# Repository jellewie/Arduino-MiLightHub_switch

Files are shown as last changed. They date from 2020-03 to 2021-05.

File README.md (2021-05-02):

# ==========

# Depricated!

# ==========

This project is stalled, and here for archieving reasons.
Altough not hardware compatible (buttons inversed) and not softSettings compatible (the order and they have changed), it is recommened to update if required. Do not start new projects with this repo this one is unsuported from now on!!
[smart-home-switch](https://github.com/jellewie/Arduino-smart-home-switch)

# ==========

# Arduino-MiLightHub_switch
 MilightHub https://github.com/sidoh/esp8266_milight_hub

# What you need
ESP8266 with esp8266_milight_hub (and it's IP ofc.)

[ESP32](https://dl.espressif.com/dl/package_esp32_index.json)

[PCB](https://easyeda.com/jellewietsma/smart-home-switch)

# How it works
Make sure the esp8266_milight_hub is already set-up and working, and you know it's IP.

Make sure you have an ESP with the PCB, you can also make one yourself but mine is linked in this project (make sure to read the schematics, they should explain themself)

Make sure to enable SecondSwitch if you have 2 sets of 4 buttons (this can't be done later).

You can either setup the settings like SSID and passwords and such in the code, but you can also just upload the sketch and power it on and set it up: 
It will go into APMODE (since it can’t connect to WIFI) connect to it and go to it's IP (192.168.4.1)
You will get a window with SSID Wi-Fi name, password, the milight hub IP, LightID, LightType, and lightGroup. Change or fill these in and submit. 
The ESP will save these settings and reboot (note that the 4 commands to send to the hub are also stored in here) (Leaving fields blank will skip updating them)

# LED feedback
There a lot of blinking patterns, but I tried to list them all here
- (Button LED) will blink every 50ms on boot if pressed (should be released on boot)
- (Button LED) will turn on when the button is pressed, and only off after it's done (or a connection timeout)

- (Main LED) will blink every 10ms if we are less then 1000ms from restarting (super long press)
- (Main LED) will blink every 100ms to show we are not connected (APMODE)
- (Main LED) will blink every 500ms to show we are trying to connect
- (Main LED) will blink every 1000ms to show that OTA (Over The Air update) is on
- (Main LED) will turn on on boot, will turn off when done
- (Main LED) will turn on when trying to connect to WIFI, will turn off when done
- (Main LED) will turn on when a long press (5000ms) is happening, will turn off when done

# Button actions
- (Button short press) execute action; send the data (saved in 'Commands#' which can be hardcoded or be set in SettingsPage) to the milight hub. This is done by default with feedback
It stops after 5 failed tries, or 2 failed connections, or 1 if send Json is wrong
- (Button long press) Hold any button for 3s and enable OTA+Web interface
- (Button extreme long press) Hold any button for 15s to reboot the ESP

# Images
Working GIF
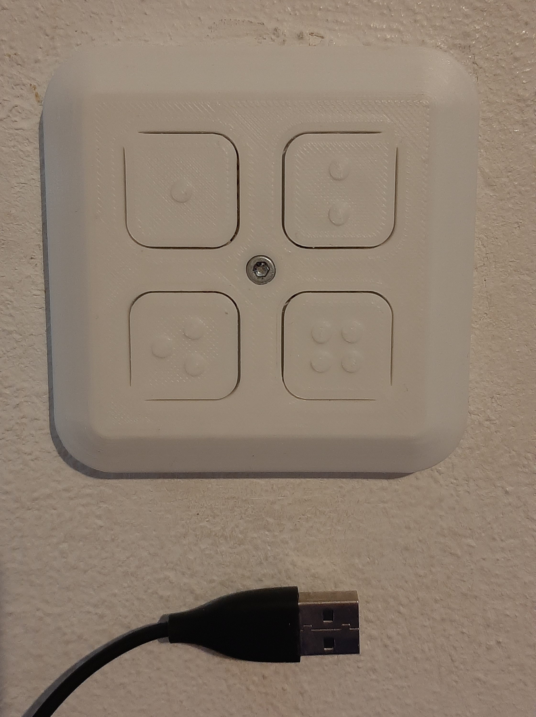
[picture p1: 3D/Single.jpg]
buttons to the wall

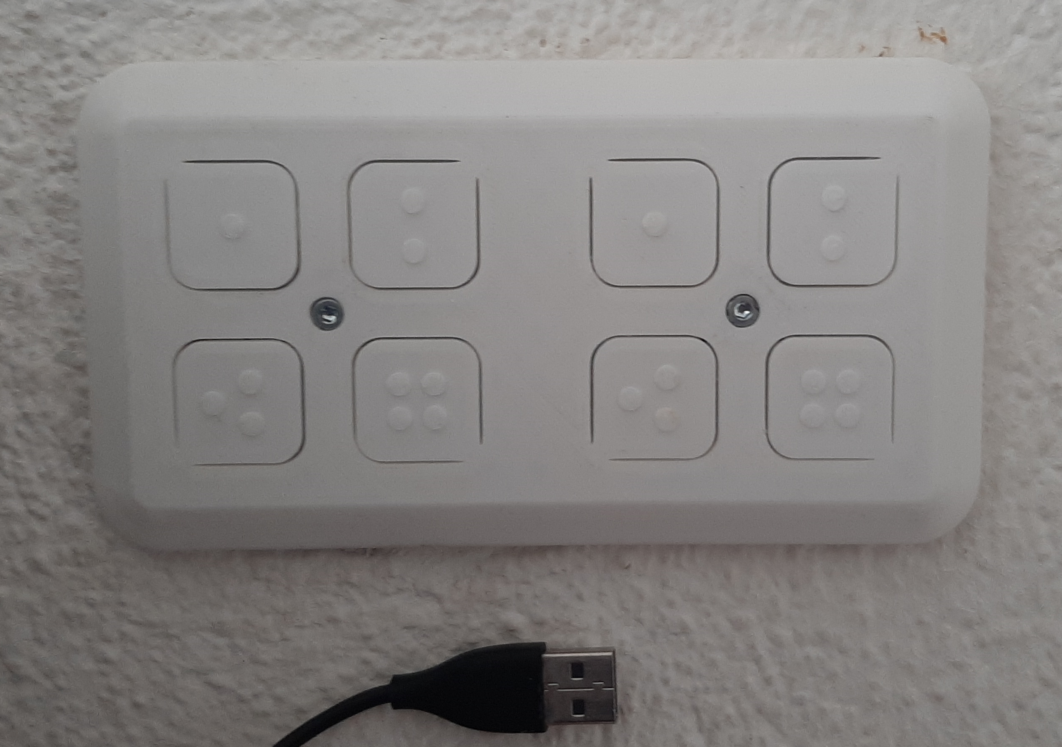
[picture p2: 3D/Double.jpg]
Double buttons settup


# How to update
1. Enable server: Press button 1 for (Button long press)
2. Go to page: IP/ota where 'IP' is its IP
3. Download the update, click on the link on the ota page, and download the latest '.bin' file
4. Upload the file, select the file and upload it
after 100% it applies it and reboots

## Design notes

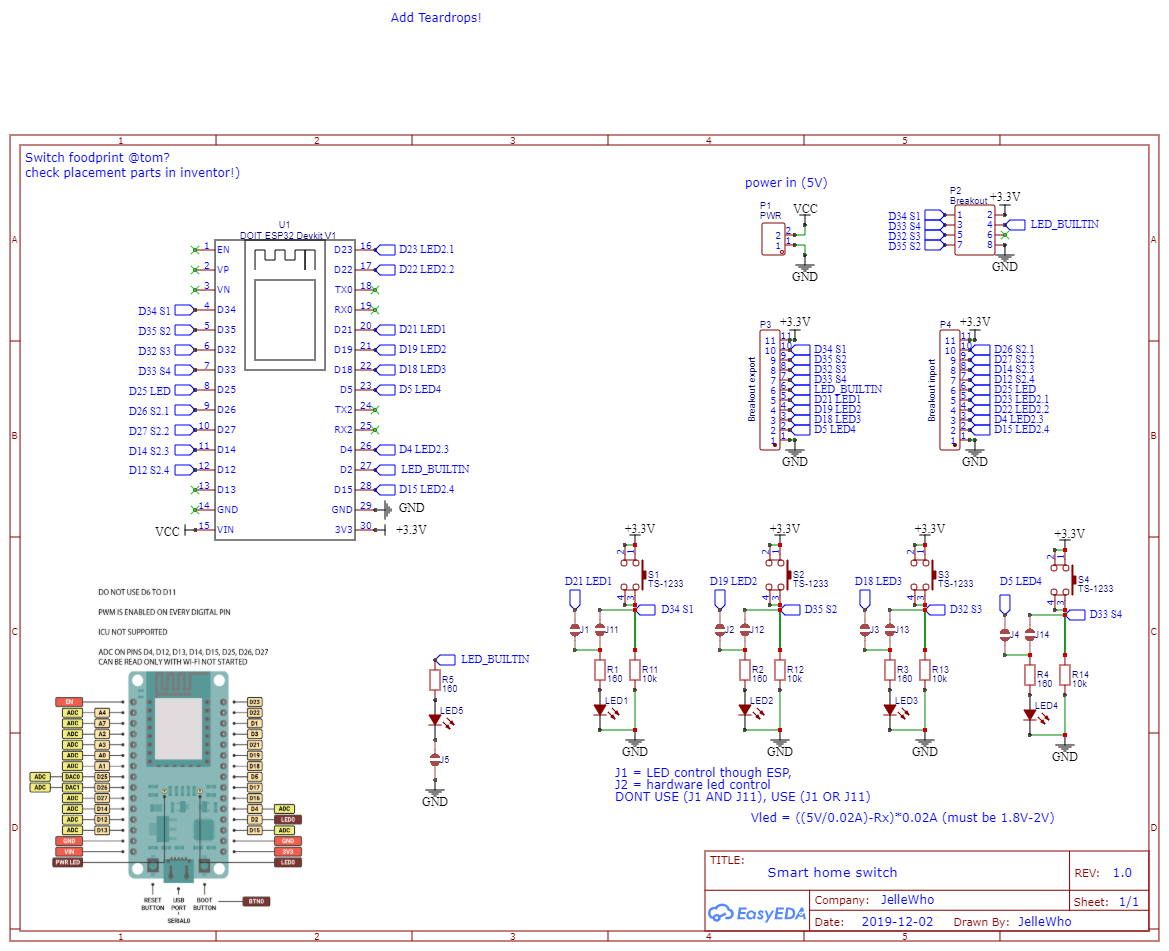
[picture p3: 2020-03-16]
PCB/Schematic_Smart home switch_Schematic_20200316124107.png

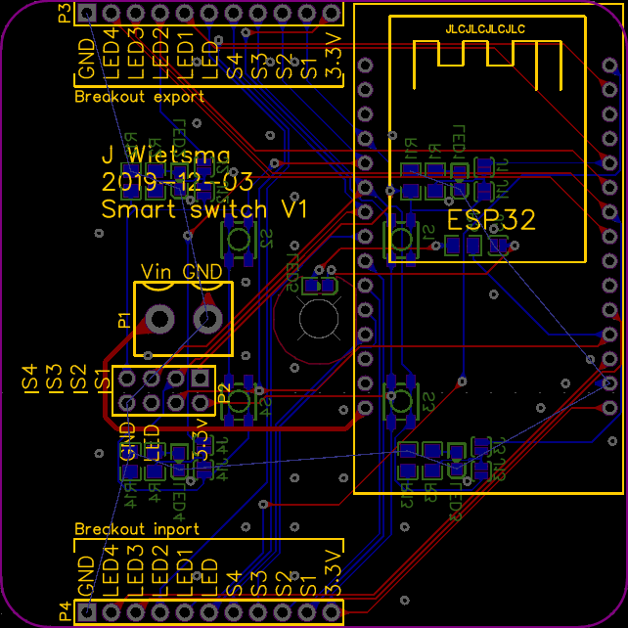
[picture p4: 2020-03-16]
PCB/PCB.png

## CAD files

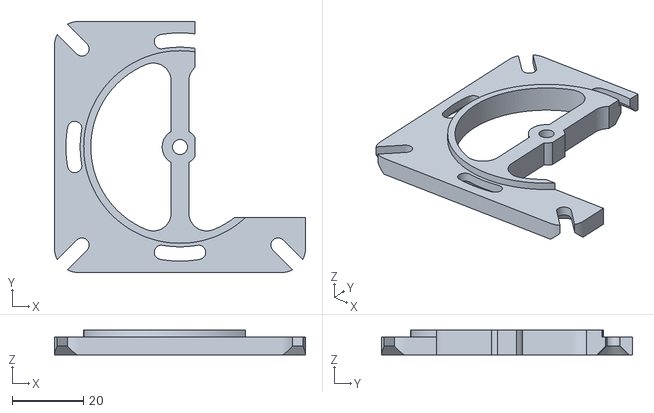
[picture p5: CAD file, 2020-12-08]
3D/V4.2 In wall single.stl
70.4 x 70.4 x 7.00

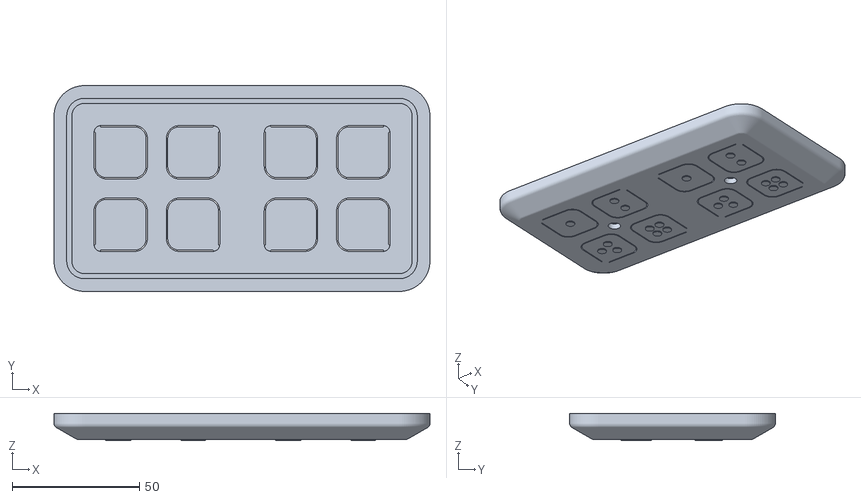
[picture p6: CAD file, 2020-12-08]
3D/V4.2 Front Double.stl
148.0 x 81.0 x 10.8

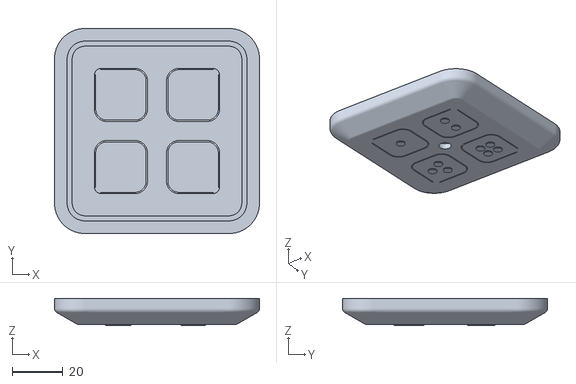
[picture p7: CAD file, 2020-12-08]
3D/V4.2 Front Single.stl
81.0 x 81.0 x 10.8

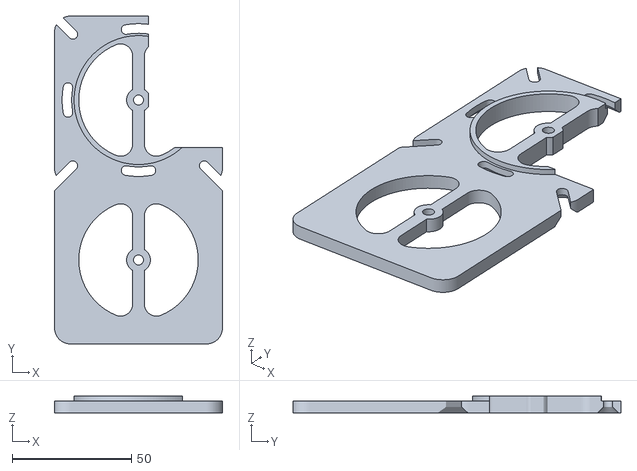
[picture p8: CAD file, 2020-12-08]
3D/V4.2 In wall double.stl
70.4 x 137.4 x 7.00

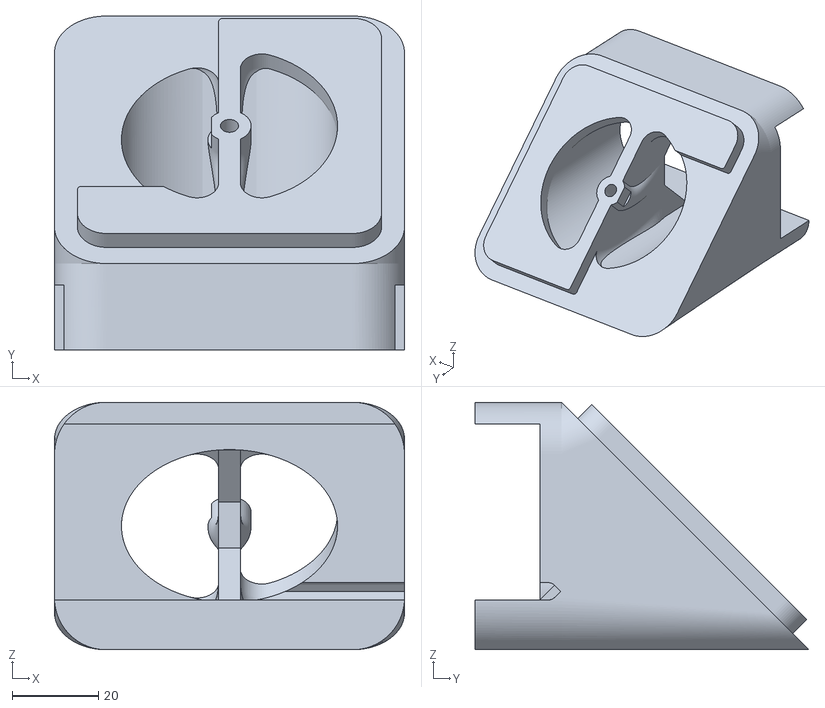
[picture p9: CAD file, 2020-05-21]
3D/BedStand.stl
81.0 x 77.3 x 57.3

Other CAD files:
3D/Bed stand.iam
3D/V4 Ikea BedStand.ipt
3D/V4.2 Assembly.iam
3D/V4.2 In wall.ipt
3D/V4.2 Plate dual.ipt
3D/V4.2 Plate single.ipt

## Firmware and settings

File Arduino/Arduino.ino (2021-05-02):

/*
  Program written by JelleWho
  Board: https://dl.espressif.com/dl/package_esp32_index.json
  Sketch from: https://github.com/jellewie/Arduino-MiLightHub_switch
*/
#if !defined(ESP32)
#error "Please check if the 'DOIT ESP32 DEVKIT V1' board is selected, which can be downloaded at https://dl.espressif.com/dl/package_esp32_index.json"
#endif

//#define SerialEnabled
//#define Button_SerialEnabled
//#define Button_SerialEnabled_CheckButton
//#define Logging

#ifdef SerialEnabled
#define Logging
#define WiFiManager_SerialEnabled
//#define Extra_SerialEnabled
#endif //SerialEnabled

#ifdef Logging
#define milight_Log
#define Speed_Log
//Convert_Log
#endif //Logging

#include "WiFiManagerBefore.h"                                  //Define what options to use/include or to hook into WiFiManager
#include "WiFiManager/WiFiManager.h"                            //Includes <WiFi> and <WebServer.h> and setups up 'WebServer server(80)' if needed      https://github.com/jellewie/Arduino-WiFiManager

#include <WiFiClient.h>                                         //Needed for sending data to devices
#include <ArduinoJson.h>                                        //This is to pack/unpack data send to the hub
#include <rom/rtc.h>                                            //This is for rtc_get_reset_reason
#include "Log.h"
#include "functions.h"
#include "miLight.h"
#include "Button/Button.h"                                      //https://github.com/jellewie/Arduino-Button

Button SwitchA[4] = {{34, {_PIN_LED: 21}}, {35, {_PIN_LED: 19}}, {32, {_PIN_LED: 18}}, {33, {_PIN_LED: 5}}}; //Bunch up the 4 buttons to be 1 switch set (Only used for reference pin pares, not which command is connected to which pin)
Button SwitchB[4] = {{26, {_PIN_LED: 23}}, {27, {_PIN_LED: 22}}, {14, {_PIN_LED: 4}}, {12, {_PIN_LED: 15}}}; // ^

byte RotationA = NORMAL;                                        //SOFT_SETTING Rotation of the PCB seen from the case
byte RotationB = UNUSED;                                        // ^           RIGHT=PCB 90° clockwise to case
MiLight LightA = {"0xF001", "rgb_cct", 1};                      //SOFT_SETTING What light to control
MiLight LightB = {"0xF002", "rgb_cct", 1};                      // ^           device_id, remote_type, group_id
const byte Amount_Buttons = sizeof(SwitchA) / sizeof(SwitchA[0]);                         //Why filling this in if we can automate that? :)
String CommandsA[Amount_Buttons] = {"{'commands':['toggle']}",                            //SOFT_SETTING what command which button sends (Example of toggle)
                                    "{'brightness':60,'color':'255,50,10','state':'On'}", //(Example of RGB)
                                    "{'brightness':255,'color_temp':999,'state':'On'}",   //(Example of CC/WW)
                                    "{'brightness':255,'color_temp':1,'state':'On'}"      //For more see https://sidoh.github.io/esp8266_milight_hub/branches/1.10.6/ Please note not all commands might be supported by your bulb
                                   };
String CommandsB[Amount_Buttons] = {"{'commands':['toggle']}",                          // ^
                                    "{'brightness':60,'color':'255,50,10','state':'On'}",
                                    "{'brightness':255,'color_temp':999,'state':'On'}",
                                    "{'brightness':255,'color_temp':1,'state':'On'}"
                                   };
#include "WiFiManagerLater.h"                                   //Define options of WiFiManager (can also be done before), but WiFiManager can also be called here (example for DoRequest)

void setup() {
#ifdef SerialEnabled
  Serial.begin(115200);
#endif //SerialEnabled
  pinMode(LED_BUILTIN, OUTPUT);
  digitalWrite(LED_BUILTIN, HIGH);
  //===========================================================================
  //Load data, since we need this to check if RotationB is !UNUSED)
  //===========================================================================
  WiFiManager.LoadData();
  //===========================================================================
  //Attach interrupts to the button pins so we can response if they change
  //===========================================================================
  attachInterrupt(SwitchA[0].PIN_Button, ISR_A0, CHANGE);
  attachInterrupt(SwitchA[1].PIN_Button, ISR_A1, CHANGE);
  attachInterrupt(SwitchA[2].PIN_Button, ISR_A2, CHANGE);
  attachInterrupt(SwitchA[3].PIN_Button, ISR_A3, CHANGE);
  if (RotationB != UNUSED) {                                    //Do not attach interrupt if this switch set is unused
    attachInterrupt(SwitchB[0].PIN_Button, ISR_B0, CHANGE);
    attachInterrupt(SwitchB[1].PIN_Button, ISR_B1, CHANGE);
    attachInterrupt(SwitchB[2].PIN_Button, ISR_B2, CHANGE);
    attachInterrupt(SwitchB[3].PIN_Button, ISR_B3, CHANGE);
  }
  //===========================================================================
  //Wait for all buttons to be NOT pressed
  //===========================================================================
  byte ButtonPressedID = 1;
  while (ButtonPressedID > 0) {
#ifdef SerialEnabled
    Serial.println("Waiting on a button(s) " + String(ButtonPressedID, BIN) + " before starting up");
#endif //SerialEnabled
    ButtonPressedID = 0;                                        //Set to NOT pressed by default, will be overwritten
    while (!TickEveryMS(50)) {}                                 //Wait here for 50ms (so an error blink would be nice)

    //Returns the button states in bits; Like 0000<button1><b2><b3><b4> where 1 is HIGH and 0 is LOW
    //Example '00001001' = Buttons 1 and 4 are HIGH (Note we count from LSB)
    byte ButtonID = 0;
    for (byte i = 0; i < Amount_Buttons; i++) {
      ButtonID = ButtonID << 1;                                 //Move bits 1 to the left (it’s like *2)
      Button_Time Value = SwitchA[i].CheckButton();
      if (Value.Pressed) {
        ButtonID += 1;                                          //Flag this button as on
        digitalWrite(SwitchA[i].PIN_LED, !digitalRead(SwitchA[i].PIN_LED));
      } else
        digitalWrite(SwitchA[i].PIN_LED, LOW);
    }
    if (RotationB != UNUSED) {
      for (byte i = 0; i < Amount_Buttons; i++) {
        ButtonID = ButtonID << 1;                               //Move bits 1 to the left (it’s like *2)
        Button_Time Value = SwitchB[i].CheckButton();
        if (Value.Pressed) {
          ButtonID += 1;                                        //Flag this button as on
          digitalWrite(SwitchB[i].PIN_LED, !digitalRead(SwitchB[i].PIN_LED));
        } else
          digitalWrite(SwitchB[i].PIN_LED, LOW);
      }
    }
    ButtonPressedID = ButtonID;                                 //Get the button state, here 1 is HIGH in the form of '0000<Button 1><2><3><4> '
  }
  for (byte i = 0; i < Amount_Buttons; i++) {
    digitalWrite(SwitchA[i].PIN_LED, LOW);                      //Make sure all LED's are off
    if (RotationB != UNUSED)
      digitalWrite(SwitchB[i].PIN_LED, LOW);                    //Make sure all LED's are off
  }
  //===========================================================================
  //Initialise server stuff
  //===========================================================================
  server.on("/log",               handle_Log);
  server.onNotFound(              HandleNotFound);
  //===========================================================================
  //Start WIFI
  //===========================================================================
  byte Answer = WiFiManager.Start();
  if (Answer != 1) {
#ifdef SerialEnabled
    Serial.println("setup error code '" + String(Answer) + "'");  delay(10);
#endif //SerialEnabled
    ESP.restart();                                              //Restart the ESP
  }
  WiFiManager.OTA_Enabled = false;
  WiFiManager.EnableSetup(true);        //Start the server (if you also need it for other stuff)
  //===========================================================================
  //Get Reset reason (This could be/is useful for power outage)
  //===========================================================================
#ifdef SerialEnabled
  if (byte Reason = GetResetReason()) {
    Serial.println("Done with boot, resetted due to " + ResetReasonToString(Reason));
  }
#endif //SerialEnabled
}
//===========================================================================
void loop() {
  if (WiFiManager.OTA_Enabled) {
    WiFiManager.RunServer();                                    //Do WIFI server stuff if needed
    BlinkEveryMs(LED_BUILTIN, 1000);                            //Blink every x MS to show OTA is on
  }

  static byte OldRotationB = RotationB;                         //Check if a second switch is added (if a rotation is set)
  if (RotationB != OldRotationB) {
    if (OldRotationB == 0 or RotationB == 0) {
#ifdef Extra_SerialEnabled
      Serial.println("ESP must reset due to Second pair added/removed");  delay(10);
#endif //Extra_SerialEnabled
      ESP.restart();                                            //Restart the ESP
    }
  }

  for (byte i = 0; i < Amount_Buttons; i++) {
    Check(SwitchA[i].CheckButton(), LightA, CommandsA[RotateButtonID(RotationA, i)], SwitchA[i].PIN_LED, RotateButtonID(RotationA, i));
    if (RotationB != UNUSED)
      Check(SwitchB[i].CheckButton(), LightB, CommandsB[RotateButtonID(RotationB, i)], SwitchB[i].PIN_LED, RotateButtonID(RotationB, i));
  }
}
//===========================================================================
void Check(Button_Time Value, MiLight Light, String Action, byte LEDpin, byte ButtonID) {
#ifdef Extra_SerialEnabled
  Serial.println("b" + String(ButtonID) + "=" + String(Value.Pressed) + " S=" + String(Value.StartPress) + " L=" + String(Value.PressedLong) + " SL=" + String(Value.StartLongPress) + " LEDpin=" + String(LEDpin));
#endif //Extra_SerialEnabled
#ifdef Speed_Log
  unsigned long StartMS = 0;
#endif //Speed_Log
  if (Value.StartPress) {                                       //If button is just pressed in
#ifdef Speed_Log
    StartMS = millis();
#endif //Speed_Log
    if (LEDpin > 0) digitalWrite(LEDpin, HIGH);                 //If a LED pin was given; Set that buttons LED on
    for (int TryAgain = 3; TryAgain > 0; TryAgain--) {          //Where TryAgain is amount of tries tries to do
      byte Feedback = SetLight(Light, Action);
      switch (Feedback) {
        case REQ_UNK:                               break;      //Keep trying again
        case REQ_SUCCES:              TryAgain = 0; break;      //We have succeeded, Do not try again
        case REQ_HUB_CONNECT_ERROR:   TryAgain = 0; break;      //The hub is unreachable, Do not try again
        case REQ_TIMEOUT:             TryAgain = 0; break;      //The hub doesn't send a responcecode back in time, some unknowns, so do not try again
        case REQ_PAGE_NOT_FOUND:      TryAgain = 0; break;      //If Json wrong format, Do not try again
        case REQ_SETUP_REQUIRED:      TryAgain = 0; break;      //If Json wrong format, Do not try again
        default:                      TryAgain = 0; break;      //Some uncatched error, Do not try again
      }
    }
    if (LEDpin > 0) digitalWrite(LEDpin, LOW);                  //If a LED pin was given; Set that buttons LED off
#ifdef Speed_Log
    Log.Add("Command processing time (start to finisch)=" + String(millis() - StartMS) + "ms");
#endif //Speed_Log
  } else if (Value.StartLongPress) {
    WiFiManager.OTA_Enabled = !WiFiManager.OTA_Enabled;         //Toggle OTA on/off
    if (LEDpin > 0) digitalWrite(LEDpin, LOW);                  //If a LED pin was given; Set that buttons LED off
  }
  if (Value.PressedLong) {                                      //If it is/was a long press
    if (Value.Pressed) {                                        //If we are still pressing
      if (Value.PressedTime > Time_ESPrestartMS - 1000) {
        if (LEDpin > 0) BlinkEveryMs(LEDpin, 10);               //If a LED pin was given; Blink that button LED
      } else
        digitalWrite(LED_BUILTIN, HIGH);
    } else {
      digitalWrite(LED_BUILTIN, LOW);
      if (LEDpin > 0) digitalWrite(LEDpin, LOW);        //If a LED pin was given; Blink that button LED
    }
  }
}
byte RotateButtonID(byte Rotation, byte i) {
  switch (Rotation) {
    case NORMAL:
      return i;
    case LEFT:
      switch (i) {
        case 0:   return 1;
        case 1:   return 3;
        case 2:   return 0;
        case 3:   return 2;
      }
    case UPSIDE_DOWN:
      switch (i) {
        case 0:   return 3;
        case 1:   return 2;
        case 2:   return 1;
        case 3:   return 0;
      }
    case RIGHT:
      switch (i) {
        case 0:   return 2;
        case 1:   return 0;
        case 2:   return 3;
        case 3:   return 1;
      }
  }
  return 0;
}
//===========================================================================
void ISR_A0() {
  SwitchA[0].Pinchange();
}
void ISR_A1() {
  SwitchA[1].Pinchange();
}
void ISR_A2() {
  SwitchA[2].Pinchange();
}
void ISR_A3() {
  SwitchA[3].Pinchange();
}
void ISR_B0() {
  SwitchB[0].Pinchange();
}
void ISR_B1() {
  SwitchB[1].Pinchange();
}
void ISR_B2() {
  SwitchB[2].Pinchange();
}
void ISR_B3() {
  SwitchB[3].Pinchange();
}

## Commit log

2020-05-21 More 3D files
    [Bed stand.iam, BedStand.ipt, BedStand.stl]
2020-05-30 Complete overhoal to work with interups and such
    Added buttuns.h for the interupts
    Updated WifiManager to the newest version.
    It's tunning on one of my single set of buttons, and all seems to work for now
2020-05-30 Updated Button.h to the latest version
2020-06-01 SecondSwitch pinout fix
    The pinout was wrong, its now fix and running on a switch I have. seems to work fine
    [Arduino.ino]
2020-09-24 Fixed some things, and cleaned things
    [Arduino.ino]
2020-09-30 Updated lib for init state
    now it no longer starts in LOW, but reads the pin and starts in the right state
2020-09-30 Remove serial print here
2020-09-30 V2! Start of work on SOFTSETTINGS
    this is a V2, this will not work with the last EEPROM version, you will need to update the EEPROM SOFTSETTINGS if you update.
    This version makes a big step towords saving everythin in EEPROM, so that 1 firmware version can be used in the future.
    TODO: Rotation of keys doesn't seem to fully work yet, will need to do some work on it, firmware has been checked to work on a rotation 1 (normal, no rotation) 4 button PCB
    [Arduino.ino]
2020-10-01 added rotation
    also fixed quite a bunch of small issues,
    Average responcetime (from button press to confirm command recieved) is 313ms (n=488) with mediaan of 302ms, a min of 38ms and a max of 3611ms
    [Arduino.ino]
2020-10-01 #V0.10.1 First web OTA release
    Everything seems to at least work fine with 1 pair in normal orentation. I personally do not use other orientations anymore, but they did work in a short test
    [Arduino.ino]
2020-10-01 Fix for second switch
    [Arduino.ino]
2020-10-04 Added logging function
    This can only be acces if server is on (Longpress button ID0 /button One)
    with the url of IP/log
2020-10-08 Updated 3D model, just sothe assembly itselfs also contains the 1 switch model
    nothing about the STL models changed btw
    [V4 Assembly.iam, V4 In wall.ipt, V4 dual in wall.ipt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]
2020-10-08 Added RGB example
    And fixed some grammar
    [Arduino.ino]
2020-10-26 Button.h update
2020-12-08 New 3D model
    updated the model to better suppor directions
    [Bed stand.iam, BedStand.ipt, V4 Assembly.iam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]
2020-12-09 Updated button lib
2020-12-09 Updated Button+WifiManager lib
2021-01-07 U[dated Button Lib (just more support for future functions)
